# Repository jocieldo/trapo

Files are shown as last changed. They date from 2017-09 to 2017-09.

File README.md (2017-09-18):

# TRAPO
## システム概要

TRAPOは赤外線距離センサーによってセンサー前方を通過した物体(自動車または歩行者)を検出します。
TRAPOセンサーには赤外線センサーが2つ搭載されています。

赤外線センサーから出力された電圧はロガーによって記録されます。
ロガーに内蔵されたArduino Unoがセンサーの出力電圧をA/D変換し、
時刻とデジタル値をSDカードに保存します。
電圧は50個/秒で記録されます。

電源はモバイルバッテリーを使用します。
21000mAhの容量で3日間の記録が可能です。

TRAPOセンサー（右下の箱にロガーを収納）
TRAPO

ロガーとバッテリー
Logger

## 交通量の記録

SDカードとモバイルバッテリーを準備します。
SDカードに保存されるログは1時間あたり約6.4MB、1日で約150MBになります。
21000mAhのモバイルバッテリーで約3日間の記録が可能です。

TRAPOセンサーやロガー及びバッテリーを収納する箱は結束バンドで欄干などに固定します。

1. ロガーにSDカードを挿入します。（ケースの構造上SDカードが抜きにくくなっています。ラジオペンチなどを使ってSDカードを引き抜いてください。）
Insert SD card
2. ロガーにTRAPOセンサーを接続します。
3. ロガーにモバイルバッテリーを接続します。
4. ロガーに電源が供給されると、時刻設定画面が表示されます。
5. 赤いボタンが「決定」です。時刻が異なる場合はこの画面で調整してください。
6. 時刻を設定するとTRAPOセンサーの出力電圧がリアルタイムで表示されます。センサーからの距離が近いと電圧が大きく、遠くなると低くなります。
（50cm以下の近距離の場合も電圧は低くなります。）
7. センサーに手をかざすなどして距離センサーが動作していることを確認してください。
8. 赤いボタンを押すと記録が開始されます。
9. 記録を開始した時刻と現在記録しているファイル名が表示されます。ファイルは1時間ごとに作られます。
10. 記録を終了する時は赤いボタンを長押しします。センサーの出力電圧がリアルタイムで表示されます。
11. この状態でモバイルバッテリーを抜いてください。

## ログデータ

TRAPOセンサーで記録されたデータはCSVファイルとして保存されます。
TRAPOセンサーに向かって右側の距離センサーが1番、左側が2番です。
CSVファイルは1時間ごとにSDカードに保存されます。
ロガーの赤いボタンを長押して記録を終了した場合は
メモリに残っているデータは強制的にSDカードに保存されます。
記録中に電源が切れた場合、メモリに残っている1時間に満たないデータは
SDカードに保存されず、消滅します。

CSVファイルの名前はDDHHMMSS.CSVになります。DDは日、HHは時、MMは分、SSは秒です。

## ログ解析
### 実行環境
#### Python3
Pythonのディストリビューションである
[Anaconda3](https://www.continuum.io/downloads)をインストールします。
Python3.xのバージョンをインストールしてください。

本プログラムはWindows、Mac、Linuxのいずれでも動作します。

#### ログ解析(counter.py)
counter.pyによってロガーで取得したログを解析します。

counter.pyにCSVファイルが入っているフォルダ指定して実行します。
フォルダ内のすべてのCSVファイル全て読み込んで処理します。
CSVファイルが入ったフォルダをcounter.pyと同じフォルダに入れておくと便利です。

counter.pyと同じフォルダに解析結果が保存されます。

### 実行手順 
1. Windowsの場合はスタートメニューから「Anaconda Prompt」を、Mac、Linuxの場合はターミナルを起動します。
2. counter.pyが入ったフォルダに移動します。
3. CSVファイルが入ったフォルダを指定してプログラムを実行します。
```
>python conter.py momiji-20170213
```
4. 通過した物体の時刻と時間ごとの交通量がファイルに保存されます。  
 詳細：momiji-20170213-traffic.csv  
 1時間毎の交通量：momiji-20170213-hourly-traffic.csv

紅葉橋
Momiji Bridge1
紅葉橋に取り付けたTRAPO
Momiji Bridge2

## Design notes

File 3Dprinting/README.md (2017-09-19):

# センサーおよびロガーのケース(3Dデータ)

## TRAPOセンサー
- 距離センサーケース: sensor_case.STL
- パイプキャップ: pipe_cap.STL
- パイプの図面: pipe.PDF, pipe.STL

## TRAPOロガー
- ロガーケース(プリント基板使用): logger_case.STL
- ロガーケース(プリント基板無し): logger_case_low.STL
- ロガーケースのフタ: logger_lid.STL
- 決定・選択ボタン: button.STL

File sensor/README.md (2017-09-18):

# TRAPO(Traffic Counter Portable)
センサー・ロガー・モバイルバッテリー
TRAPO Sensor and Logger

ロガー
TRAPO Logger

## TRAPOセンサー

### 部品
- [シャープ測距モジュール　GP2Y0A710K][3]
- アルミ角パイプ 20mm x 20mm x 1200mm
- [ゴムブッシュ9φ][8]
- LANケーブル(5mを半分にカット)
- センサーケース(3Dプリント)2個
- キャップ(3Dプリント)2個

### 配線(シャープ測距モジュール = LANケーブル)

センサー1(右)

- 1(黄)GND = 青(4)
- 2(青)Vcc = 白茶(7)
- 3(黒)Vcc = 白茶(7)
- 4(白)Vo  = 白青(5)
- 5(赤)GND = 青(4)

センサー2(左)

- 1(黄)GND = 緑(6)
- 2(青)Vcc = 茶(8)
- 3(黒)Vcc = 茶(8)
- 4(白)Vo  = 白緑(3)
- 5(赤)GND = 緑(6)

### LANケーブルの配線
1. 角パイプを1200mmに切断し穴を開ける。
pipe
2. 真ん中の穴にブッシュゴムを取り付ける。
rubberbush
3. 真ん中の穴からLANケーブルを通し、右側の穴まで通す。
pipe and LAN cable
4. 角パイプ半分より少し長めのところでLANケーブルの被覆を剥き、ケーブルに結び目を作る。オレンジ・白オレンジのケーブルは切断する。
strip LAN cable
knot
5. 両端からケーブルを引き出す。
右側からは青・白青・白茶のケーブルを引き出す。
right side
左側からは緑・白緑・茶のケーブルを引き出す。
left side
6. センサーとケースを取り付ける。
right sensor and case
left sensor and case
7. 側面の穴からケーブルを引き出し、センサーをケースに押し込む。
8. 側面の穴から引き出したケーブルを、穴に戻してキャップで蓋をする。 

## TRAPOロガー
Logger Inside
Arduino and Shield
TRAPO Logger

### 部品
- [Arduino Uno][7]
- [Adafruit Data Logging Shield][1]
- [LANコネクタDIP化基板][2]
- [LCDキャラクタディスプレイモジュール（16x2行バックライト無）][4]
- [可変抵抗][5]（LCDのコントラスト調整用）
- [タクトスイッチ][6](赤・白)
- ケース(3Dプリント)
- フタ(3Dプリント)
- ボタン(3Dプリント)(赤・黄)
- プリント基板(自作) 

### 配線
#### LANコネクタDIP化基板 = Data Logging Shield

- 1(白橙) = nc
- 2(橙)   = nc
- 3(白緑) = AnalogIn 1
- 4(青)   = GND
- 5(白青) = AnalogIn 0
- 6(緑)   = GND
- 7(白茶) = 5V
- 8(茶)   = 5V

#### LCDキャラクタディスプレイモジュール = Data Logging Shield
-  1 VDD = 5V
-  2 VSS = GND
-  3 VO  = 可変抵抗(2)
-  4 RS  = D7
-  5 R/W = GND
-  6 E   = D6
-  7 DB0 = nc
-  8 DB1 = nc
-  9 DB2 = nc
- 10 DB3 = nc
- 11 DB4 = D5
- 12 DB5 = D4
- 13 DB6 = D3
- 14 DB7 = D2

#### 可変抵抗
- 1 = GND
- 2 = LCD(3)
- 3 = 5V

#### タクトスイッチ = Data Logging Shield
決定ボタン(赤)

- T1-T2 = D8
- T3-T4 = GND

選択ボタン(赤以外)

- T1-T2 = D9
- T3-T4 = GND

#### Data Logging Shieldへの部品配置と配線

部品面
Shield Top

半田面（Data Logging Shieldの「SCK」「MISO」「MOSI」3つのジャンパを
ハンダ付けしてショートしてください。）
Shield Top

### プリント基板
pcb
pcb and wiring

制作時間を短縮するためにプリント基板を作りました。

Logger PCB

PCBEで設計し[ユニクラフト](https://unicraft-jp.com)に発注しました。
logger.zipは発注時に送ったデータです。

※Data Logging Shieldの「SCK」「MISO」「MOSI」3つのジャンパを
ハンダ付けしてショートしてください。

参考にしたサイト：[PCBEによる基板設計の手引き][10]

### ファームウェア(Arduino)

ファームウェアにはRTCのライブラリが必要です。
「RTClib by Adafruit」のバージョン1.2.0をインストールしてください。

Arduino IDEの「スケッチ」「ライブラリを管理...」から検索してください。

[1]: https://www.adafruit.com/product/1141
[2]: http://akizukidenshi.com/catalog/g/gP-05409/
[3]: http://akizukidenshi.com/catalog/g/gI-03157/
[4]: http://akizukidenshi.com/catalog/g/gP-00040/
[5]: http://akizukidenshi.com/catalog/g/gP-06063/
[6]: http://akizukidenshi.com/catalog/g/gP-03646/
[7]: https://store.arduino.cc/usa/arduino-uno-rev3
[8]: https://www.marutsu.co.jp/pc/i/14644/
[10]: http://ifdl.jp/akita/plan/pcbeguide/

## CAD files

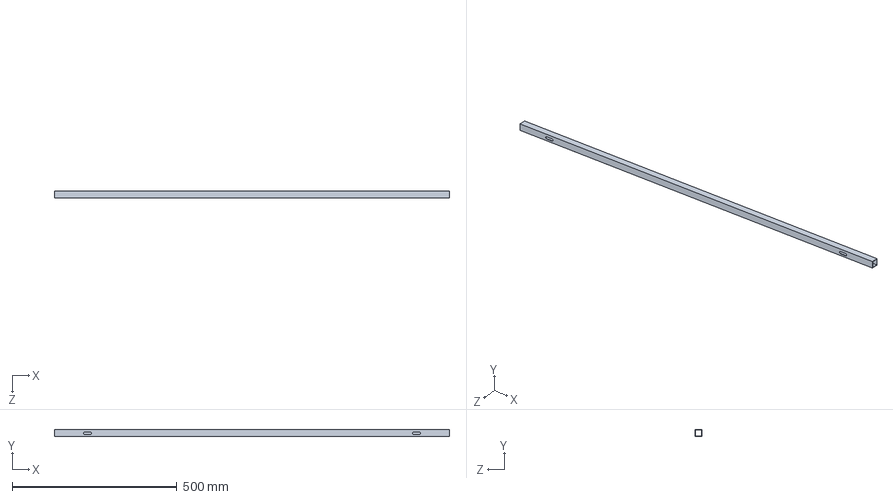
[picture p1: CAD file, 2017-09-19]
3Dprinting/pipe.SLDPRT
1200.0 x 20.0 x 20.0 mm

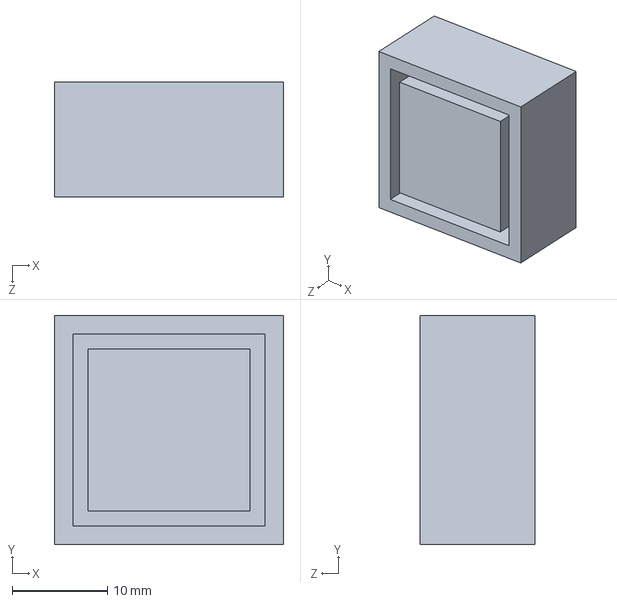
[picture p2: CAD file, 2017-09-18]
3Dprinting/pipe_cap.SLDPRT
24.0 x 24.0 x 12.0 mm

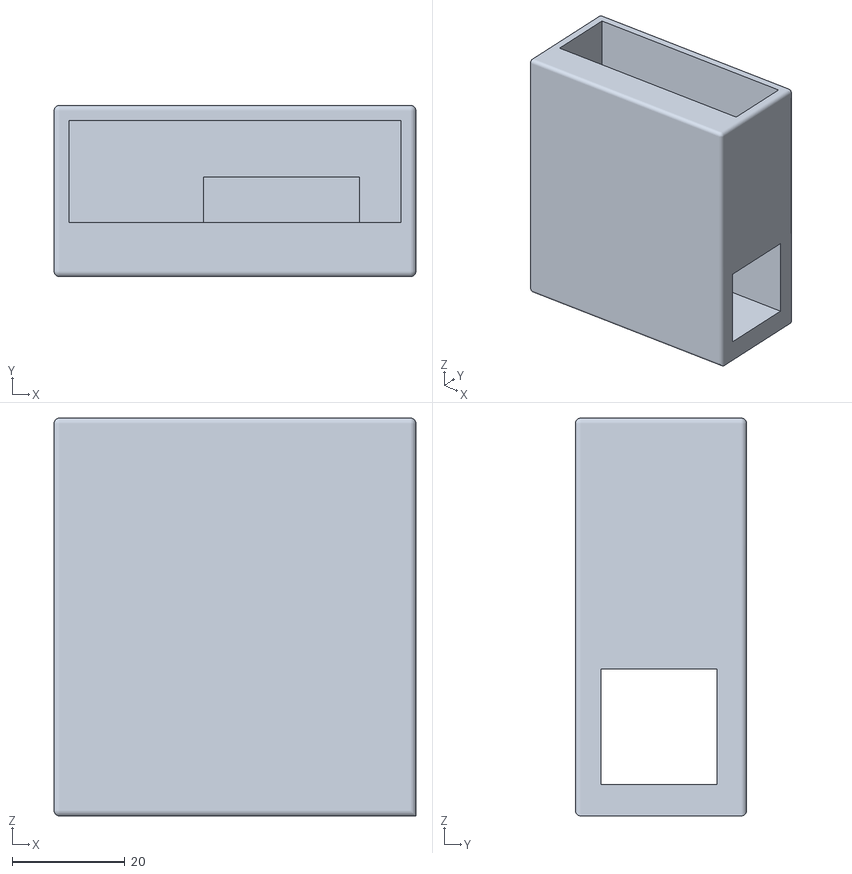
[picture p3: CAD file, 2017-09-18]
3Dprinting/sensor_case.STL
64.2 x 30.4 x 70.6

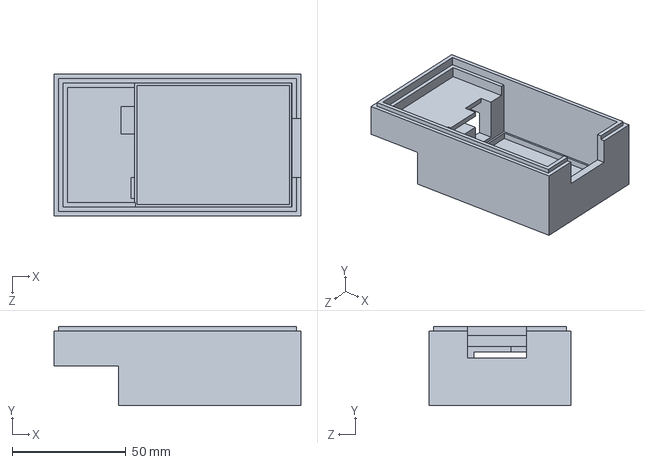
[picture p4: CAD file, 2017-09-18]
3Dprinting/logger_case_low.SLDPRT
108.8 x 35.0 x 62.5 mm

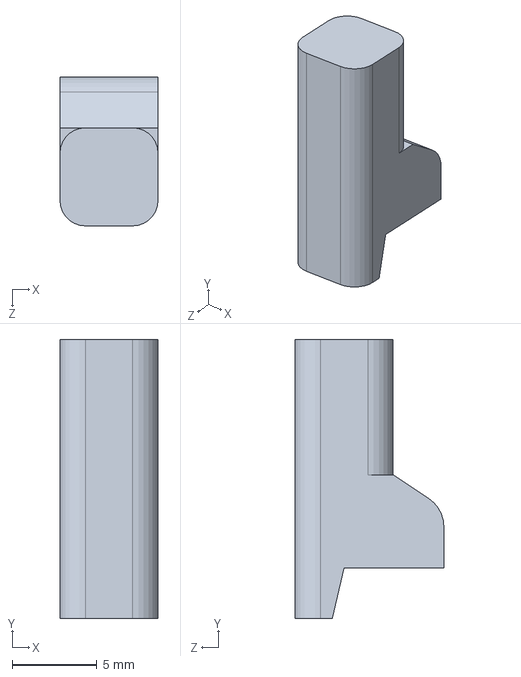
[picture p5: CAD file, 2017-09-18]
3Dprinting/button.SLDPRT
5.80 x 16.5 x 8.80 mm

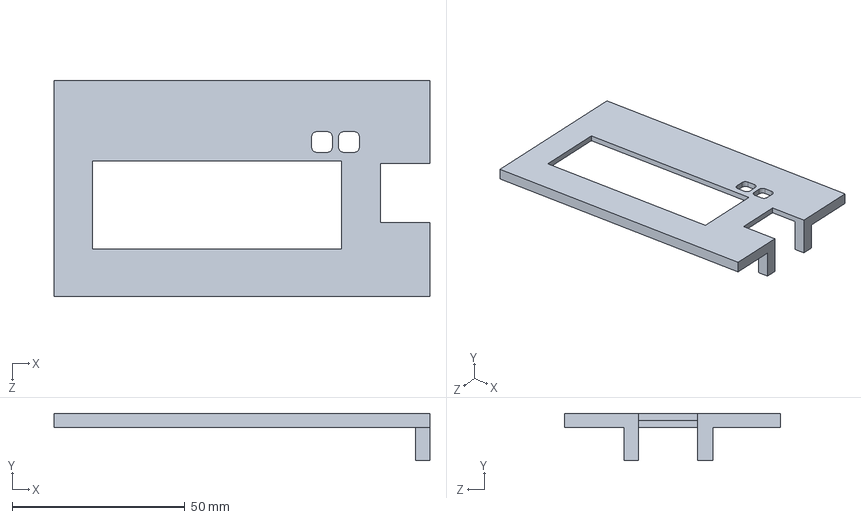
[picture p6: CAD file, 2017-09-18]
3Dprinting/logger_lid.SLDPRT
108.8 x 13.6 x 62.5 mm

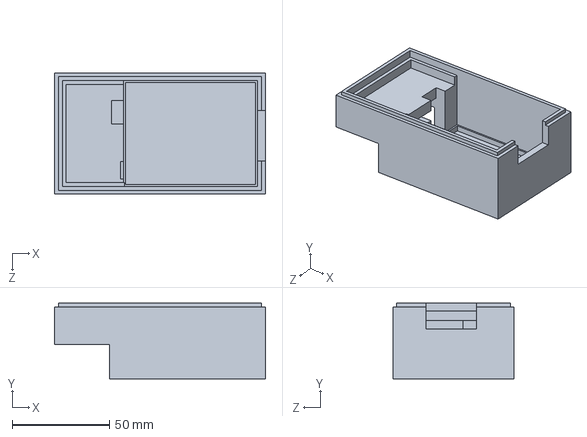
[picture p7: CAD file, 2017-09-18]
3Dprinting/logger_case.SLDPRT
108.8 x 39.0 x 62.5 mm

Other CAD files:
3Dprinting/button.STL
3Dprinting/logger_case.STL
3Dprinting/logger_case_low.STL
3Dprinting/logger_lid.STL
3Dprinting/pipe.STL
3Dprinting/pipe_cap.STL

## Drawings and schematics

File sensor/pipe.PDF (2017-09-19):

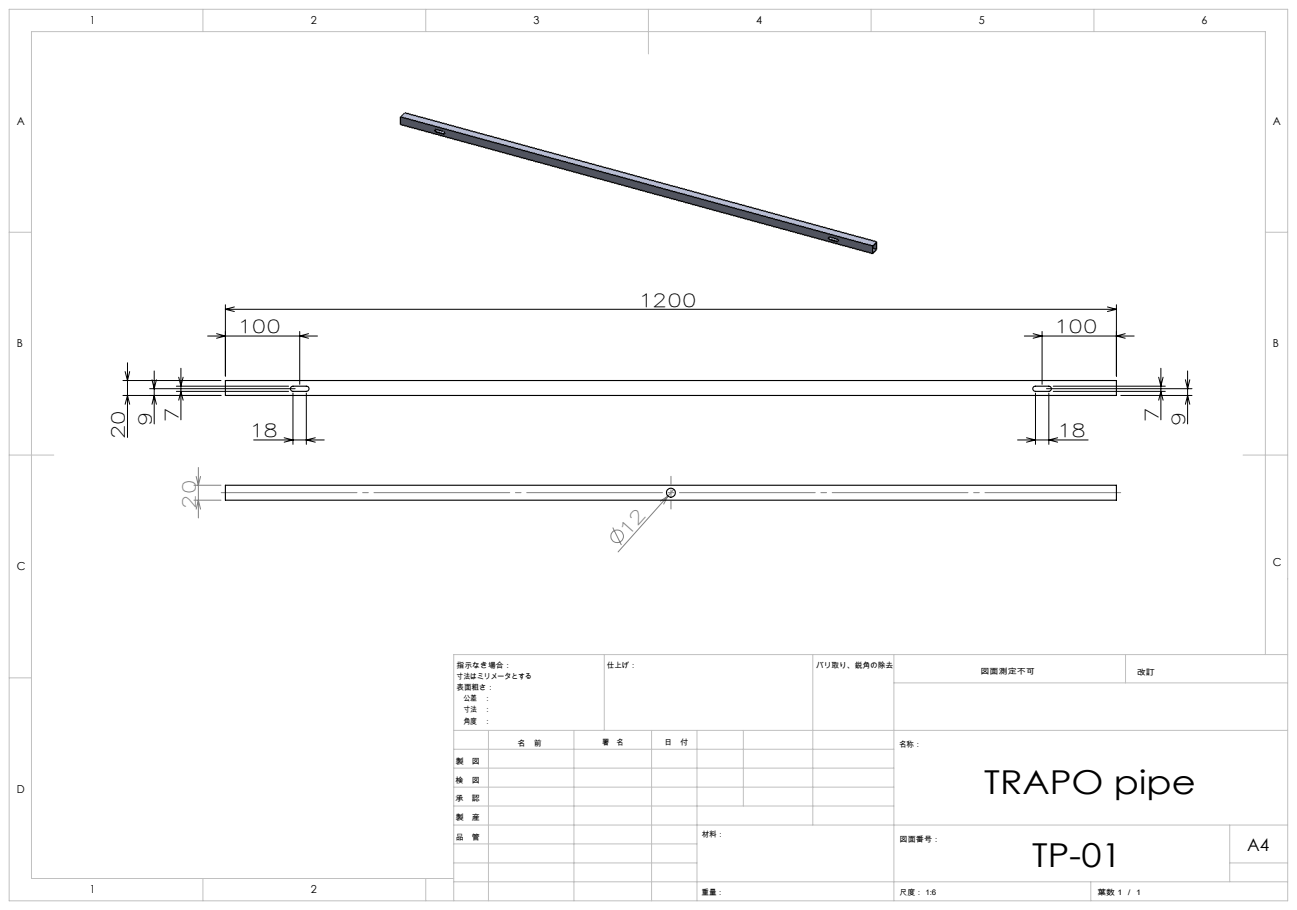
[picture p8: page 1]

名　前 | 署　名 | 日　付 | | | | 名称： TRAPO pipe

製　図
検　図
承　認
製　産
品　管 | | | | 材料： | 図面番号： TP-01 | A4

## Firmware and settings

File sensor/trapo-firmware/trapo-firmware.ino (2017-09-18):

#include <Wire.h>
#include <LiquidCrystal.h>
#include <stdio.h>
#include <RTClib.h>
#include <SD.h>

#define VER_MAJ 0x01
#define VER_MIN 0x01

// select rtc chip type: DS1307 or PCF8523
//#define DS1307  // old logging shield
#define PCF8523

#define TIME_PAR_FILE 60 // minutes
#define CTIME_STRING_BUFFER 20

// Akizuki LCD
// 1:VDD
// 2:VSS
// 3:VO contrast
// 4:RS
// 5:R/W
// 6:E
// 7-14:DB0-DB17
//
// LiquidCrystal(rs, enable, d4, d5, d6, d7)
// LiquidCrystal(rs, rw, enable, d4, d5, d6, d7)
// LiquidCrystal(rs, enable, d0, d1, d2, d3, d4, d5, d6, d7)
// LiquidCrystal(rs, rw, enable, d0, d1, d2, d3, d4, d5, d6, d7)
LiquidCrystal lcd(7,6,5,4,3,2);

// Switch
int swSet = 8;
int swSelect = 9;

// Sensor
int sensor0 = 0;
int sensor1 = 1;

uint16_t year = 2017;
uint8_t month = 7;
uint8_t day = 29;
uint8_t hour = 7;
uint8_t minute = 51;
const int chipSelect = 10;

#ifdef DS1307
#define VER_SHIELD 0xa
RTC_DS1307 RTC;
#endif

#ifdef PCF8523
#define VER_SHIELD 0xb
RTC_PCF8523 RTC;
#endif

//=====================================
// initialize
//=====================================
void setup() {
  byte tm[7];
  char date[20];

  pinMode(swSet, INPUT_PULLUP);
  pinMode(swSelect, INPUT_PULLUP);

  // initialize LCD
  lcd.begin(16,2);
  lcd.setCursor(0,0);
  
  // initialize serial
  Serial.begin(9600);
  while (!Serial);
  
  // initialize RTC
  Serial.print(F("Initializing RTC..."));
  Wire.begin();
  RTC.begin();
  #ifdef DS1307
  if (!RTC.isrunning()) {
    RTC.adjust(DateTime(F(__DATE__),F(__TIME__)));
  }
  #endif
  #ifdef PCF8523
  if (!RTC.initialized()) {
    RTC.adjust(DateTime(F(__DATE__),F(__TIME__)));
  }
  #endif  
  Serial.println(F("ok."));
  DateTime now = RTC.now();
  sprintf(date, "%d-%02d-%02d %02d:%02d:%02d", now.year(), now.month(), now.day(),
          now.hour(), now.minute(), now.second());
  Serial.println(date);

  // initialize SD card
  Serial.print(F("Initializing SD card..."));

  if (!SD.begin(chipSelect)) {
    Serial.println(F("Card failed, or no present"));
    fatalError("SD card failed  ");
  }
  SdFile::dateTimeCallback( &dateTime );
  Serial.println(F("ok."));

  sprintf(date, "Version %x.%02x%x", VER_MAJ, VER_MIN, VER_SHIELD);
  lcd.setCursor(0,0);
  lcd.print(date);
  delay(1000);
  
  int yes;
  int no;
  while (true) {
    now = RTC.now();
    sprintf(date, "%d-%02d-%02d %02d:%02d",
            now.year(), now.month(), now.day(),
            now.hour(), now.minute());
    lcd.setCursor(0,0);
    lcd.print(date);
    lcd.setCursor(0,1);
    lcd.print(F("correct? [Y:red]"));

    int i;
    for (i = 0; i < 20; i++) {
      yes = digitalRead(swSet);
      no  = digitalRead(swSelect);
      delay(50);
      if (yes == 0 || no == 0) break;
    }
    if (no == 0) {
      lcd.setCursor(0,1);
      lcd.print(F("set date time..."));
      delay(2000);
      lcd.clear();
      while (digitalRead(swSet) == 0 || digitalRead(swSelect) == 0);
      adjustDateTime();
      lcd.setCursor(0,1);
      lcd.print(F("setting...      "));
      delay(1000);
      while (digitalRead(swSet) == 0 || digitalRead(swSelect) == 0);
    }
    if (yes == 0) {
      lcd.setCursor(0,1);
      lcd.print(F("please wait...  "));
      delay(2000);
      lcd.clear();
      while (digitalRead(swSet) == 0 || digitalRead(swSelect) == 0);
      break;
    }
  }
}

//============================================
// main loop
//============================================
void loop() {
  char date[20];
  char filename[24];
  long i;

  // display voltage
  while (true) {
    DateTime now = RTC.now();
    sprintf(date, "%d-%02d-%02d %02d:%02d:%02d",
            now.year(), now.month(), now.day(),
            now.hour(), now.minute(), now.second());
    lcd.setCursor(0,0);
    lcd.print(date);
    lcd.setCursor(0,1);
    float s0 = (float)analogRead(sensor0)*5.0/1023.0;
    float s1 = (float)analogRead(sensor1)*5.0/1023.0;
    lcd.print(s0,2);
    lcd.print(F(" "));
    lcd.print(s1,2);
    lcd.print(F("  [red]"));
    long wait_time = 100000;
    for (i = 0; i < wait_time; i++) {
      if (digitalRead(swSet) == 0) break;
    }
    if (i != wait_time) break;
  }
  delay(200);
  while (digitalRead(swSet) == 0);

  // logging
  while (true) {
    DateTime now = RTC.now();
    sprintf(date, "%d-%02d-%02d %02d:%02d:%02d",
            now.year(), now.month(), now.day(),
            now.hour(), now.minute(), now.second());
    sprintf(filename, "%02d%02d%02d%02d.CSV",
            now.day(), now.hour(), now.minute(), now.second());
    Serial.print(date);
    Serial.print(' ');
    Serial.println(filename);
    lcd.setCursor(0,1);
    lcd.print(date);
    int n = getData(TIME_PAR_FILE, filename);
    if (n < 0) {
      lcd.setCursor(0,1);
      fatalError("file failed     ");
    }
    if (n == 0) {
      Serial.println(F("stop"));
      lcd.setCursor(0,1);
      lcd.print(F("stop            "));
      while (digitalRead(swSet) == 0);
      break;
    }
  }
}

//============================================
// abortLogging()
//============================================
#define ABORT_LIMIT 200
int abortDelay = ABORT_LIMIT;
bool abortLogging()
{
  if (digitalRead(swSet) == 0) {
    abortDelay--;
    if (abortDelay == 0) {
      abortDelay = ABORT_LIMIT;
      return true;
    }
  }
  else {
    abortDelay = ABORT_LIMIT;
  }

  return false;
}

//============================================
// getData()
//============================================
int getData(int min_par_file, char *filename)
{
  int j;
  long num = 0;
  char date[20];
  int pre_min = 70;
  byte sec = 0;
  
  File dataFile = SD.open(filename, FILE_WRITE);
  if (dataFile) {
    while (true) {
      int s0 = analogRead(sensor0);
      int s1 = analogRead(sensor1);

      DateTime now = RTC.now();
      int cur_min = now.minute();
      if (pre_min == 70) {
        pre_min = cur_min;
        sec = now.second();
      }
      if (cur_min != pre_min && sec == now.second()) {
        pre_min = cur_min;
        min_par_file--;
        if (min_par_file == 0) break;
      }
      sprintf(date, "%d-%02d-%02dT%02d:%02d:%02d",
              now.year(), now.month(), now.day(),
              now.hour(), now.minute(), now.second());
      dataFile.print(date);
      dataFile.print(",");
      dataFile.print(num);
      num++;
      dataFile.print(",");
      dataFile.print(s0);
      dataFile.print(",");
      dataFile.println(s1);
      if (abortLogging()) {
        dataFile.close();
        return 0;
      }
      delay(17);
    }
    dataFile.close();
  }
  else {
    Serial.print(F("error opening "));
    Serial.println(filename);
    fatalError("can't open file ");
    return -1;
  }
  return 1;
}

//============================================
// adjustDateTime()
//============================================
void adjustDateTime()
{
  char date[32];
  int dt = 500;
  int cnt = 5;

  DateTime now = RTC.now();
 
  lcd.noCursor();
  lcd.clear();
  lcd.print(F("initialize time?"));
  lcd.setCursor(0,1);
  lcd.print(F("[Y:red]"));
  delay(2000);
  while (true) {
    if (digitalRead(swSet) == 0) {
      lcd.clear();
      lcd.print(F("initializing..."));
      now = DateTime(F(__DATE__),F(__TIME__));
      break;
    }
    if (digitalRead(swSelect) == 0) {
      break;
    }
  }
  while (digitalRead(swSet) == 0 || digitalRead(swSelect) == 0);

  year = now.year();
  month = now.month();
  day = now.day();
  hour = now.hour();
  minute = now.minute();
  
  sprintf(date, "%d-%02d-%02d %02d:%02d", year, month, day, hour, minute);
  lcd.cursor();
  lcd.home();
  lcd.clear();
  lcd.print(date);

  // adjust year
  dt = 500;
  cnt = 5;
  while (true) {
    lcd.setCursor(3,0);
    if (digitalRead(swSet) == 0) break;
    if (digitalRead(swSelect) == 0) {
      year++;
      lcd.setCursor(0,0);
      lcd.print(year);
      lcd.setCursor(3,0);
      delay(dt);
      cnt--;
      if (cnt == 0) dt = 100;  // fast
    }
    else {
      cnt = 5;
      dt = 500; // slow
    }
  }
  delay(150);
  while (digitalRead(swSet) == 0);

  // adjust month
  cnt = 5;
  dt = 500;
  while (true) {
    lcd.setCursor(6,0);
    if (digitalRead(swSet) == 0) break;
    if (digitalRead(swSelect) == 0) {
      month++;
      if (month == 13) month = 1;
      lcd.setCursor(5,0);
      if (month < 10) {
        lcd.print(0);
      }
      lcd.print(month);
      lcd.setCursor(6,0);
      delay(dt);
      cnt--;
      if (cnt == 0) dt = 100;
    }
    else {
      cnt = 5;
      dt = 500;
    }
  }
  delay(150);
  while (digitalRead(swSet) == 0);

  // adust day
  cnt = 5;
  dt = 500;
  while (true) {
    lcd.setCursor(9,0);
    if (digitalRead(swSet) == 0) break;
    if (digitalRead(swSelect) == 0) {
      day++;
      if (month == 4 || month == 6 || month == 9 || month == 11) {
        if (day == 31) day = 1;
      }
      else if (month == 2) {
        int y = year;
        // check leap year 
        if ((y % 4) == 0 && (y % 100) != 0 && (y % 400) == 0) {
          if (day == 30) day = 1;
        }
        else {
          if (day == 29) day = 1;
        }
      }
      else {
        if (day == 32) day = 1;
      }

      lcd.setCursor(8,0);
      if (day < 10) {
        lcd.print(0);
      }
      lcd.print(day);
      lcd.setCursor(9,0);
      delay(dt);
      cnt--;
      if (cnt == 0) dt = 100;
    }
    else {
      cnt = 5;
      dt = 500;
    }
  }
  delay(150);
  while (digitalRead(swSet) == 0);

  // adjust hour
  cnt = 5;
  dt = 500;
  while (1) {
    lcd.setCursor(12,0);
    if (digitalRead(swSet) == 0) break;
    if (digitalRead(swSelect) == 0) {
      hour++;
      if (hour == 24) hour = 0;
      lcd.setCursor(11,0);
      if (hour < 10) {
        lcd.print(0);
      }
      lcd.print(hour);
      lcd.setCursor(12,0);
      delay(dt);
      cnt--;
      if (cnt == 0) dt = 100;
    }
    else {
      cnt = 5;
      dt = 500;
    }
  }
  delay(150);
  while (digitalRead(swSet) == 0);

  // adjust minute
  cnt = 5;
  dt = 500;
  while (1) {
    lcd.setCursor(15,0);
    if (digitalRead(swSet) == 0) break;
    if (digitalRead(swSelect) == 0) {
      minute++;
      if (minute == 60) minute = 0;
      lcd.setCursor(14,0);
      if (minute < 10) {
        lcd.print(0);
      }
      lcd.print(minute);
      lcd.setCursor(15,0);
      delay(dt);
      cnt--;
      if (cnt == 0) dt = 100;
    }
    else {
      cnt = 5;
      dt = 500;
    }
  }
  RTC.adjust(DateTime(year, month, day, hour, minute, 0));
  lcd.noCursor();
}

//============================================
// fatalError()
//============================================
void fatalError(const char *message)
{
  char date[32];

  DateTime now = RTC.now();
  sprintf(date, "%d-%02d-%02dT%02d:%02d:%02d",
          now.year(), now.month(), now.day(),
          now.hour(), now.minute(), now.second());
  lcd.setCursor(0,0);
  lcd.print(date);
  lcd.setCursor(0,1);
  lcd.print(message);
  while (true) {
    lcd.noDisplay();
    delay(500);
    lcd.display();
    delay(500);
  }
}

//============================================
// dateTime()
// for SD card time stamp
//============================================
void dateTime(uint16_t* date, uint16_t* time)
{
  DateTime now = RTC.now();
  *date = FAT_DATE(now.year(), now.month(), now.day());
  *time = FAT_TIME(now.hour(), now.minute(), now.second());
}

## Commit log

2017-09-18 TRAPO sensor and logger
2017-09-18 3D printing
    [button.SLDPRT, button.STL, cap.SLDPRT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]
2017-09-19 3Dデータの説明を追加
    [pipe.SLDPRT, pipe.STL, pipe_cap.SLDPRT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]
